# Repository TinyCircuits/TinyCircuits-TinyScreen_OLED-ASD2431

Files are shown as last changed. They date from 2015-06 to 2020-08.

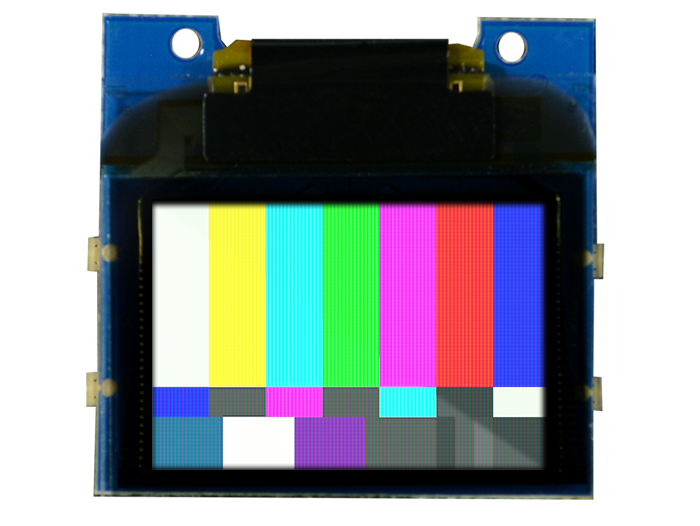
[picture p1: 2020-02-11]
images/ASD2431-R-Tutorial-Image-01.2.png

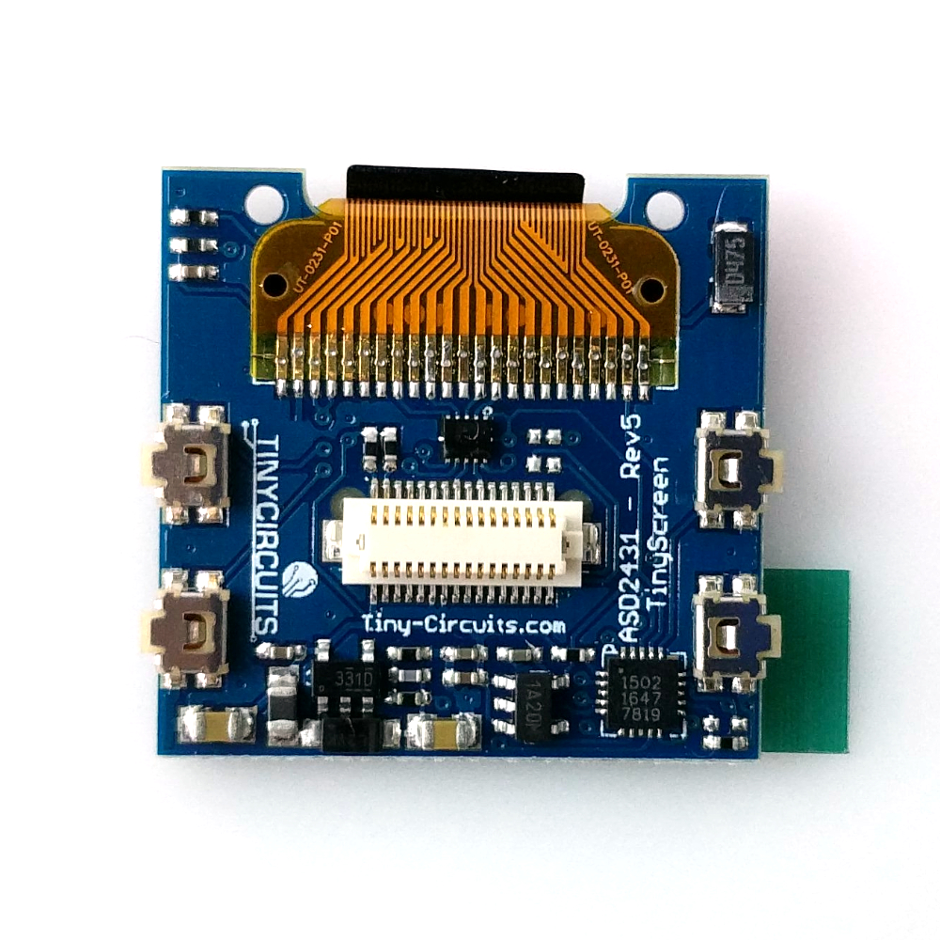
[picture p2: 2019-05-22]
images/ASD2431-R-Tutorial-Image-012.jpg

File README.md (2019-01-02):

# TinyCircuits TinyScreen OLED Display
# ASD2431 Rev6

The design files are located under design_files/ for the TinyCircuits TinyScreen PCB Rev6.  This is a TinyShield board that includes a 96x64 Color OLED Display.  

Format is in Cadsoft Eagle format - Eagle version 6.2 was used for the original design.

For more infomation on this, check out the product page at TinyCircuits.com: https://tinycircuits.com/collections/leds-displays/products/tinyscreen

# License:

Design by TinyCircuits.
All design files are released under the Creative Commons Attribution Share-Alike 3.0 License, see the following link for details: http://creativecommons.org/licenses/by-sa/3.0

All text above must be included in any redistribution or derived design

This project uses designs and concepts developed as part of the Arduino project and the LilyPad project.  The TinyCircuits design files themselves (schematics, PCB and libraries) are not directly derived from these works' design files and have been created new, however the concepts and basic architecture behind the TinyDuino and TinyLily products are derived and we thank the hard work of the organizations below for their contributions to open-source hardware:
  
Original Arduino Uno Design by Team Arduino

LilyPad Arduino Design by Leah Buechley and Sparkfun Electronics

Please support the open-source hardware community

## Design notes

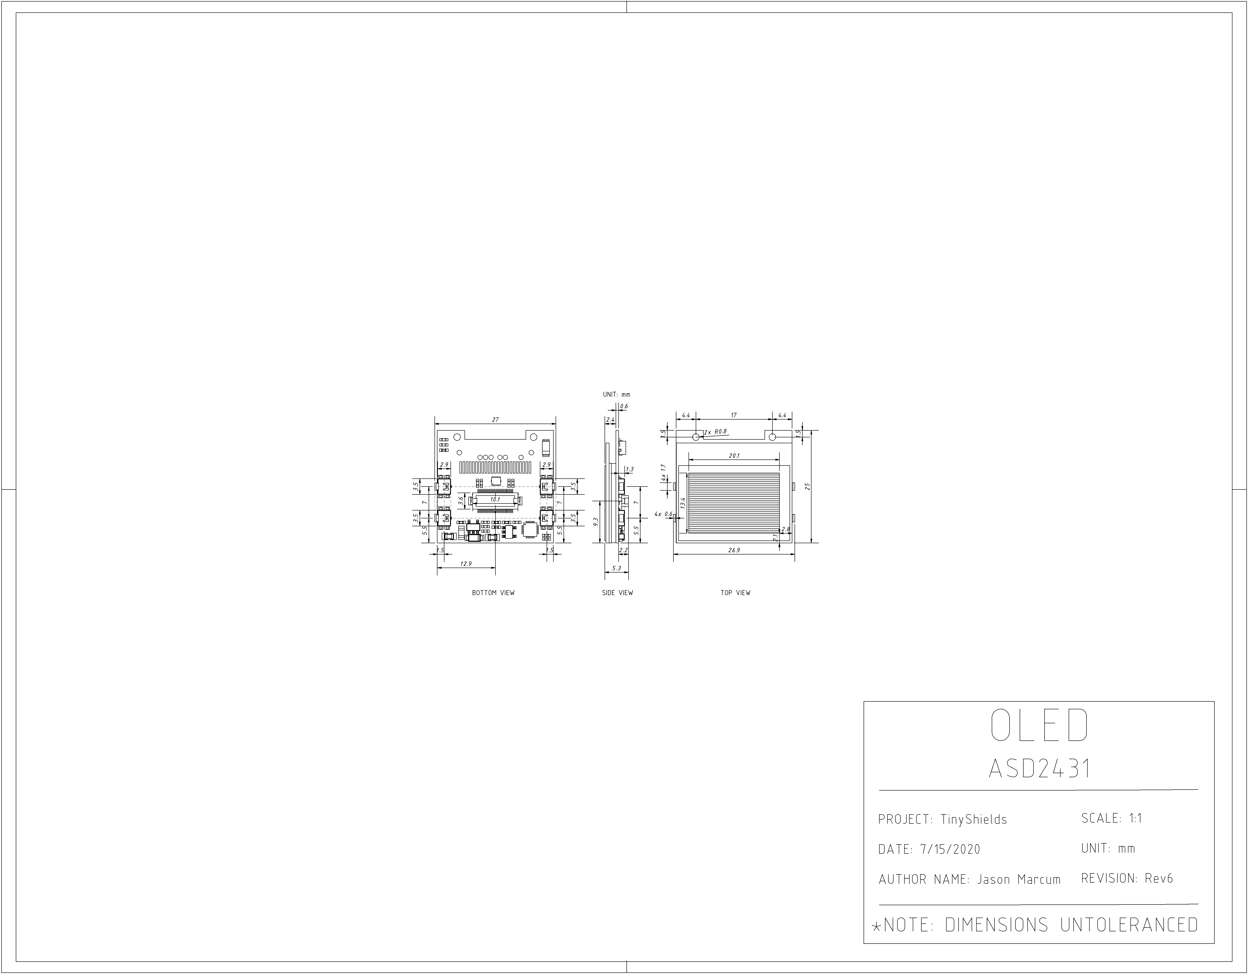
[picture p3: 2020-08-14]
cad/TinyShield_OLED_ASD2431_REV6-DETAILED_DRAWING-PNG.png

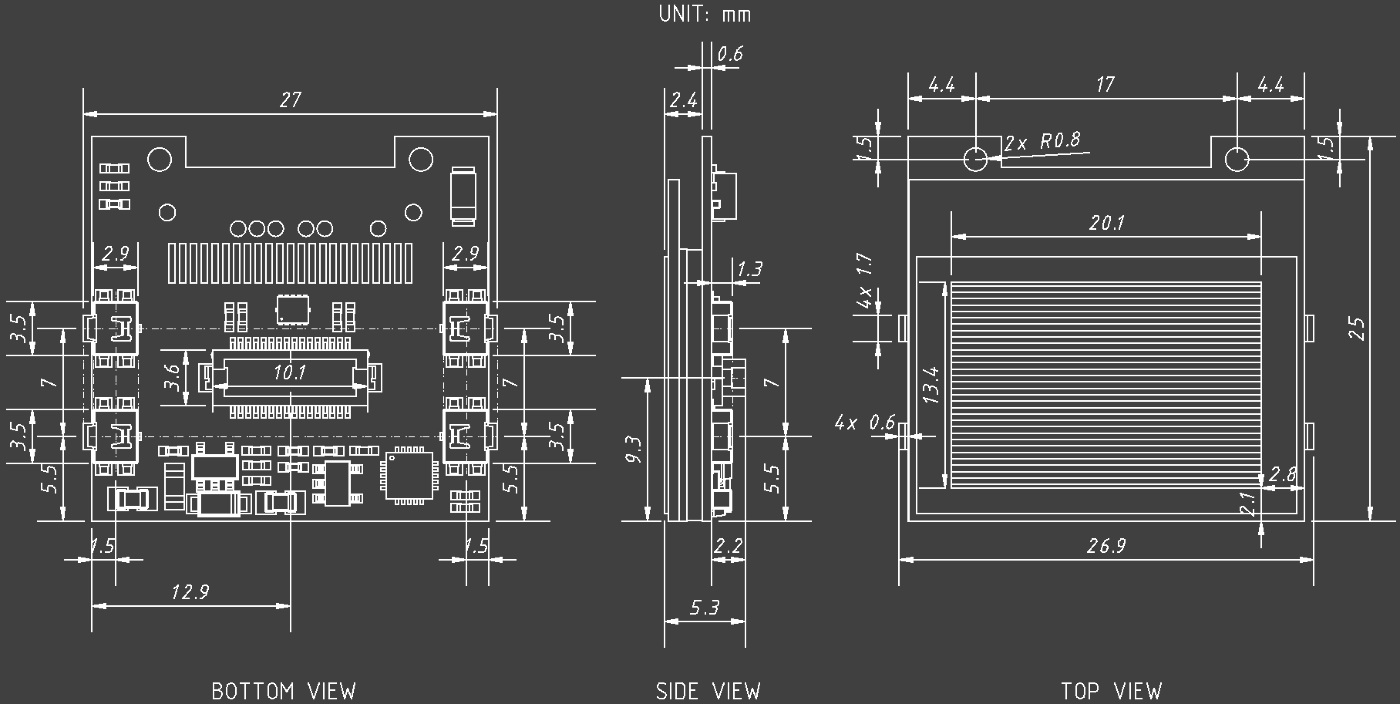
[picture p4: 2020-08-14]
cad/TinyShield_OLED_ASD2431_REV6-DETAILED_DRAWING_COMPACT-PNG.png

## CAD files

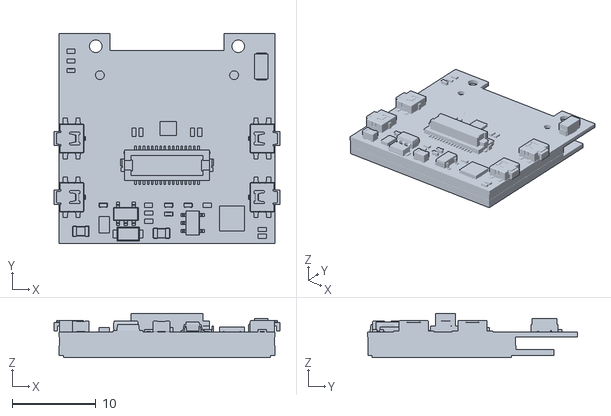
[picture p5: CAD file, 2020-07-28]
cad/TinyShield_OLED_ASD2431_REV6-STL.stl
26.9 x 25.0 x 5.25

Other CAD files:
cad/TinyShield_OLED_ASD2431_REV6-DETAILED_DRAWING-DXF.dxf

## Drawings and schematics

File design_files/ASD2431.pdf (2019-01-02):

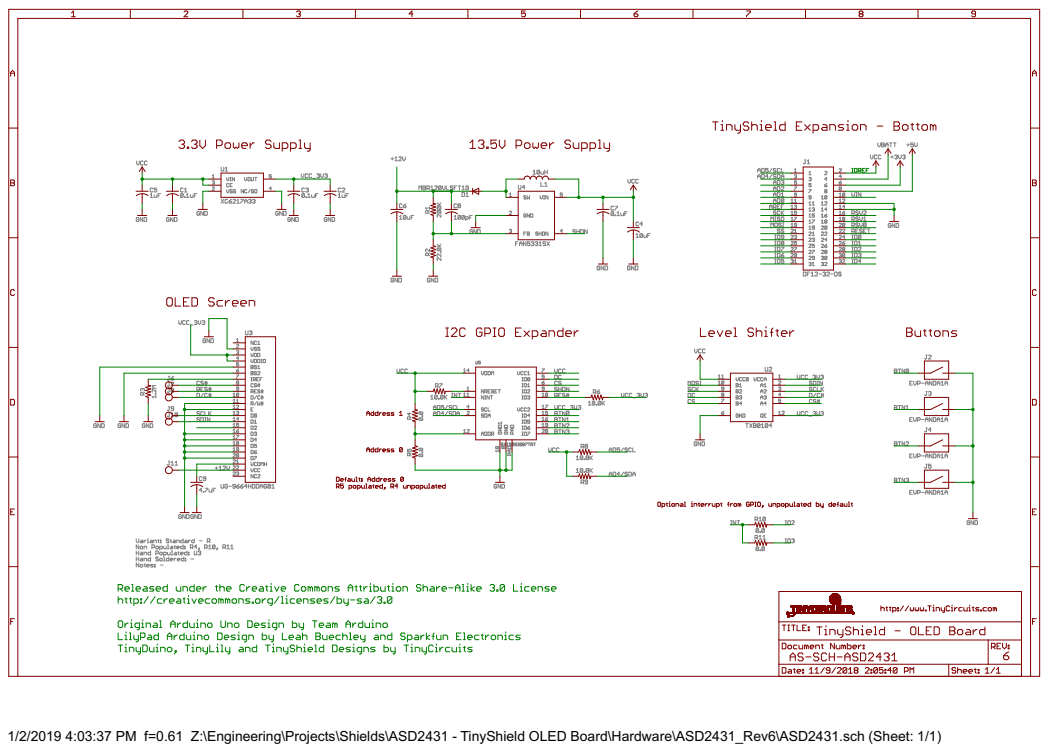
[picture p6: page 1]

1/2/2019 4:03:37 PM f=0.61 Z:\Engineering\Projects\Shields\ASD2431 - TinyShield OLED Board\Hardware\ASD2431_Rev6\ASD2431.sch (Sheet: 1/1)

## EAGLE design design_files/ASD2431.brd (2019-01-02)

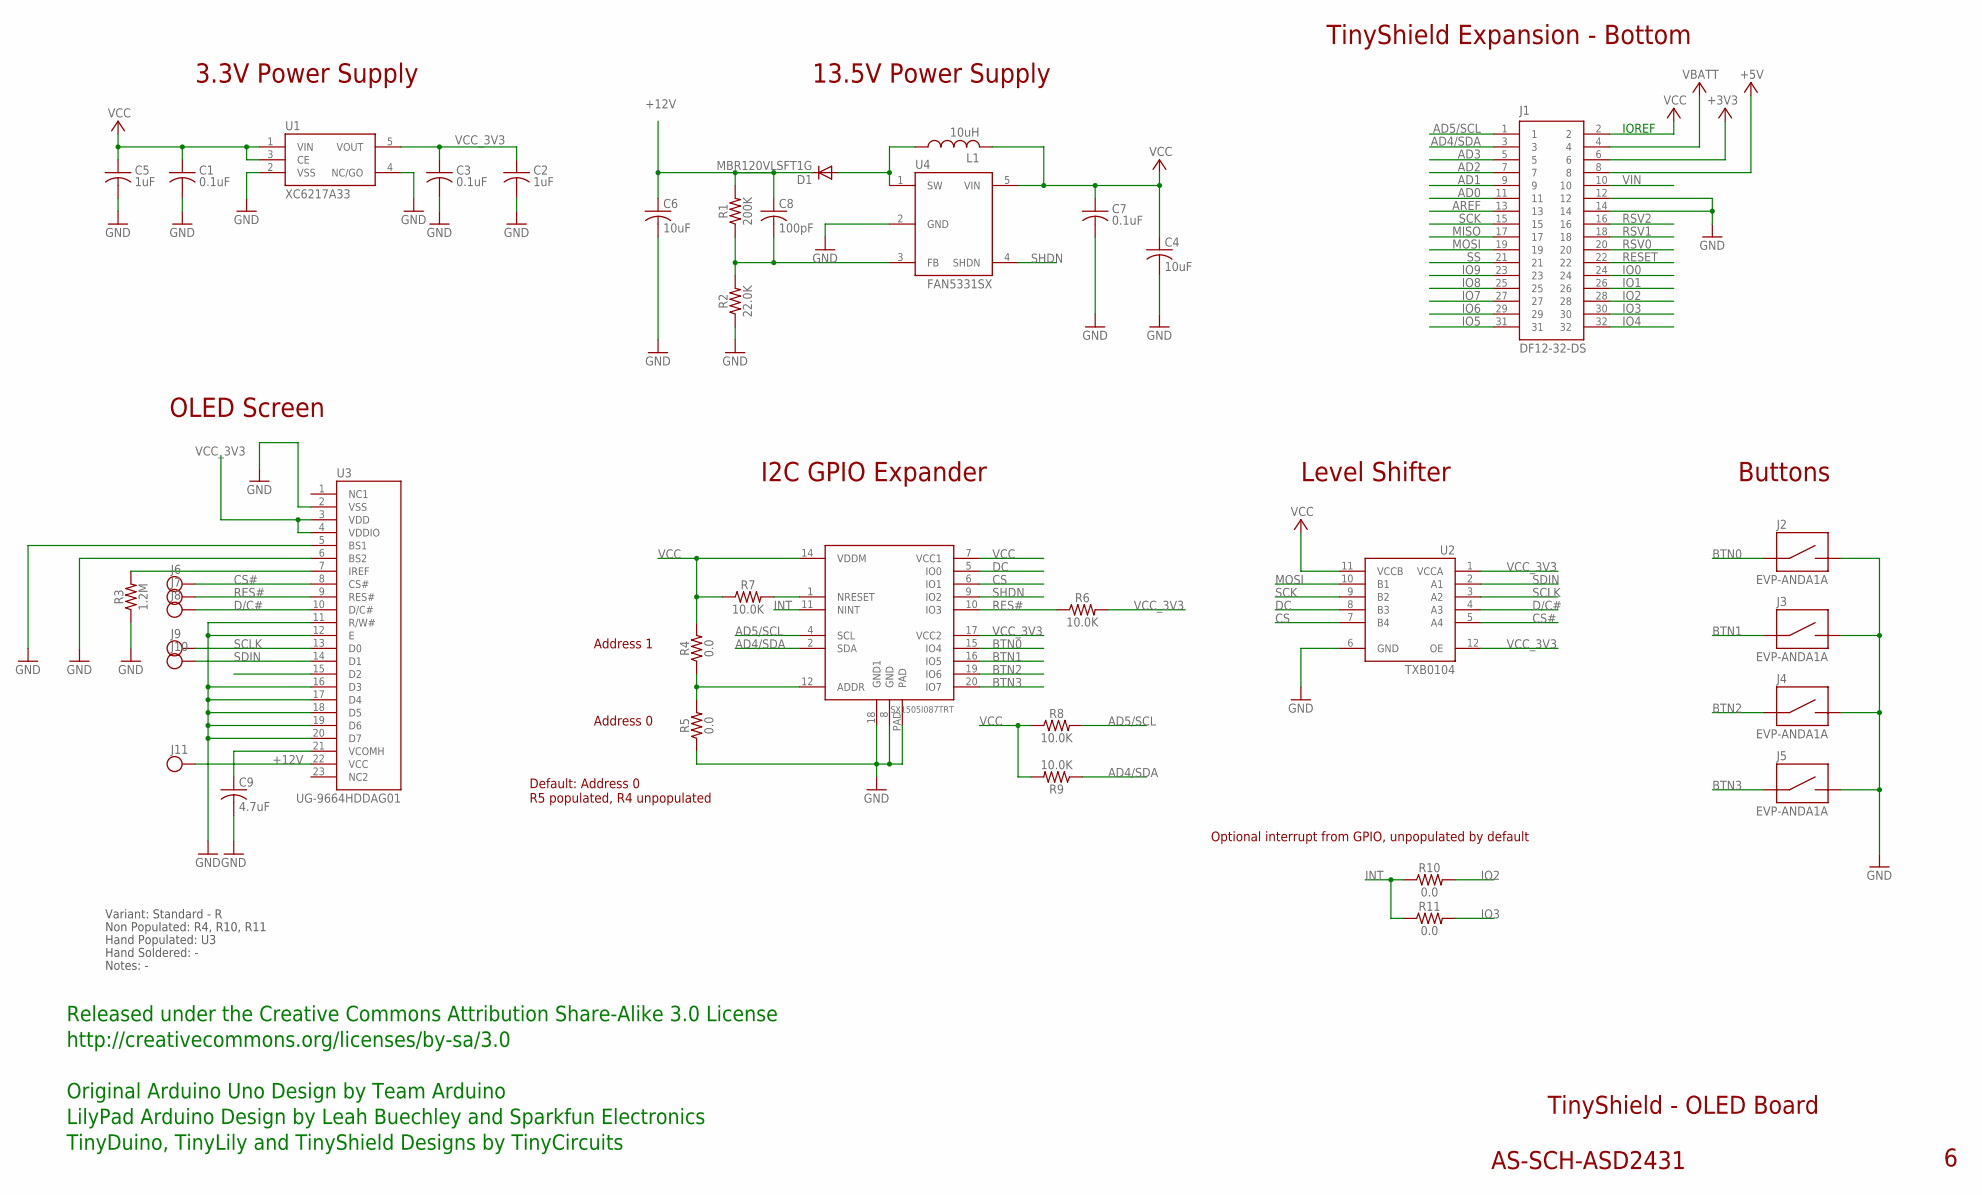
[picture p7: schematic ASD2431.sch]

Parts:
C1, C3, C7: 0.1uF; C0402; PARTNO AS-ITM-00008
C2, C5: 1uF; C0402; PARTNO AS-ITM-00105
C4, C6: 10uF; C0805; PARTNO AS-ITM-00045
C8: 100pF; 0402; PARTNO AS-ITM-00148
C9: 4.7uF; 1206_CAP_TANT; PARTNO AS-ITM-00232
D1: MBR120VLSFT1G; SOD-123FL
J1: DF12-32-DS; PARTNO AS-ITM-00012
J2, J3, J4, J5: EVP-ANDA1A; PTS840GKP; PARTNO AS-ITM-00236
J6, J7, J8, J9, J10, J11: TEST_POINT; TEST_POINT_1MM
L1: 10uH; R0805
R1: 200K; 0402; PARTNO AS-ITM-00178
R2: 22.0K; 0402; PARTNO AS-ITM-00147
R3: 1.2M; 0402; PARTNO AS-ITM-00280
R4, R5: 0.0; 0402
R6: 10.0K; 0402
R7, R8, R9: 10.0K; 0402; PARTNO AS-ITM-00032
R10, R11: 0.0; 0402; PARTNO AS-ITM-00076
U1: XC6217A33; SOT-25; PARTNO AS-ITM-00249
U2: TXB0104; UQFN-12
U3: UG-9664HDDAG01; OLED_DISPLAY
U4: FAN5331SX; SOT-23
U5: SX1505I087TRT; QFN-UT20

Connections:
+3V3: J1.6
+5V: J1.8
+12V: C6.1, C8.1, D1.C, J11.P$1, R1.2, U3.22 (VCC)
AD0: J1.11
AD1: J1.9
AD2: J1.7
AD3: J1.5
AD4/SDA: J1.3, R9.1, U5.2 (SDA)
AD5/SCL: J1.1, R8.2, U5.4 (SCL)
AREF: J1.13
BTN0: J2.1, J2.2 (1), U5.15 (IO4)
BTN1: J3.1, J3.2 (1), U5.16 (IO5)
BTN2: J4.1, J4.2 (1), U5.19 (IO6)
BTN3: J5.1, J5.2 (1), U5.20 (IO7)
CS: U2.7 (B4), U5.6 (IO1)
CS#: J6.P$1, U2.5 (A4), U3.8 (CS#)
D/C#: J8.P$1, U2.4 (A3), U3.10 (D/C#)
DC: U2.8 (B3), U5.5 (IO0)
GND: C1.2, C2.2, C3.2, C4.2, C5.2, C6.2, C7.2, C9.2, J1.12, J1.14, J2.3 (2), J2.4 (2), J3.3 (2), J3.4 (2), J4.3 (2), J4.4 (2), J5.3 (2), J5.4 (2), R2.1, R3.1, R5.1, U1.2 (VSS), U1.4 (NC/GO), U2.6 (GND), U3.2 (VSS), U3.5 (BS1), U3.6 (BS2), U3.11 (R/W#), U3.12 (E), U3.16 (D3), U3.17 (D4), U3.18 (D5), U3.19 (D6), U3.20 (D7), U4.2 (GND), U5.8 (GND), U5.18 (GND1), U5.PAD
INT: R10.1, R11.1, U5.11 (NINT)
IO0: J1.24
IO1: J1.26
IO2: J1.28, R10.2
IO3: J1.30, R11.2
IO4: J1.32
IO5: J1.31
IO6: J1.29
IO7: J1.27
IO8: J1.25
IO9: J1.23
MISO: J1.17
MOSI: J1.19, U2.10 (B1)
unnamed: R7.2, U5.1 (NRESET)
unnamed: D1.A, L1.1, U4.1 (SW)
unnamed: C8.2, R1.1, R2.2, U4.3 (FB)
unnamed: R3.2, U3.7 (IREF)
unnamed: C9.1, U3.21 (VCOMH)
unnamed: R4.1, R5.2, U5.12 (ADDR)
RES#: J7.P$1, R6.1, U3.9 (RES#), U5.10 (IO3)
RESET: J1.22
RSV0: J1.20
RSV1: J1.18
RSV2: J1.16
SCK: J1.15, U2.9 (B2)
SCLK: J9.P$1, U2.3 (A2), U3.13 (D0)
SDIN: J10.P$1, U2.2 (A1), U3.14 (D1)
SHDN: U4.4 (SHDN), U5.9 (IO2)
SS: J1.21
VBATT: J1.4
VCC: C1.1, C4.1, C5.1, C7.1, J1.2, L1.2, R4.2, R7.1, R8.1, R9.2, U1.1 (VIN), U1.3 (CE), U2.11 (VCCB), U4.5 (VIN), U5.7 (VCC1), U5.14 (VDDM)
VCC_3V3: C2.1, C3.1, R6.2, U1.5 (VOUT), U2.1 (VCCA), U2.12 (OE), U3.3 (VDD), U3.4 (VDDIO), U5.17 (VCC2)
VIN: J1.10

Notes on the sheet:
TinyShield Expansion - Bottom
TinyShield - OLED Board
AS-SCH-ASD2431
IOREF
Released under the Creative Commons Attribution Share-Alike 3.0 License
http://creativecommons.org/licenses/by-sa/3.0
LilyPad Arduino Design by Leah Buechley and Sparkfun Electronics
TinyDuino, TinyLily and TinyShield Designs by TinyCircuits
Original Arduino Uno Design by Team Arduino
3.3V Power Supply
13.5V Power Supply
OLED Screen
Level Shifter
I2C GPIO Expander
Buttons
Address 0
Address 1
Default: Address 0 R5 populated, R4 unpopulated
Optional interrupt from GPIO, unpopulated by default
Non Populated: R4, R10, R11
Hand Populated: U3
Hand Soldered: -
Notes: -
Variant: Standard - R

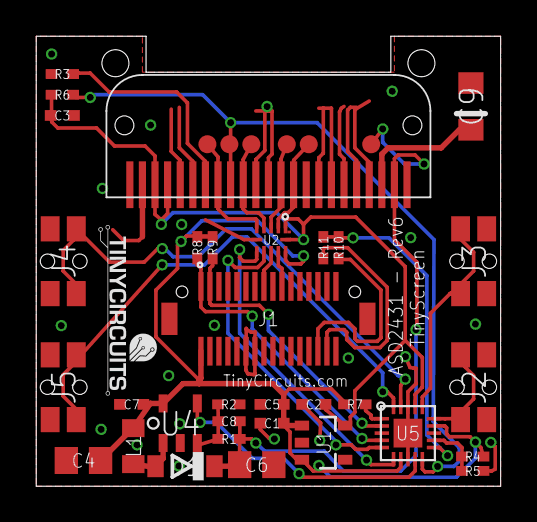
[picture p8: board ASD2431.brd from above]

Board: 2 copper layers, 25.8 x 25.0 mm, 39 parts (0 on the bottom side), 29 nets.

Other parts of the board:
U$1: DOCFIELD-TINYCIRCUITS-PCB

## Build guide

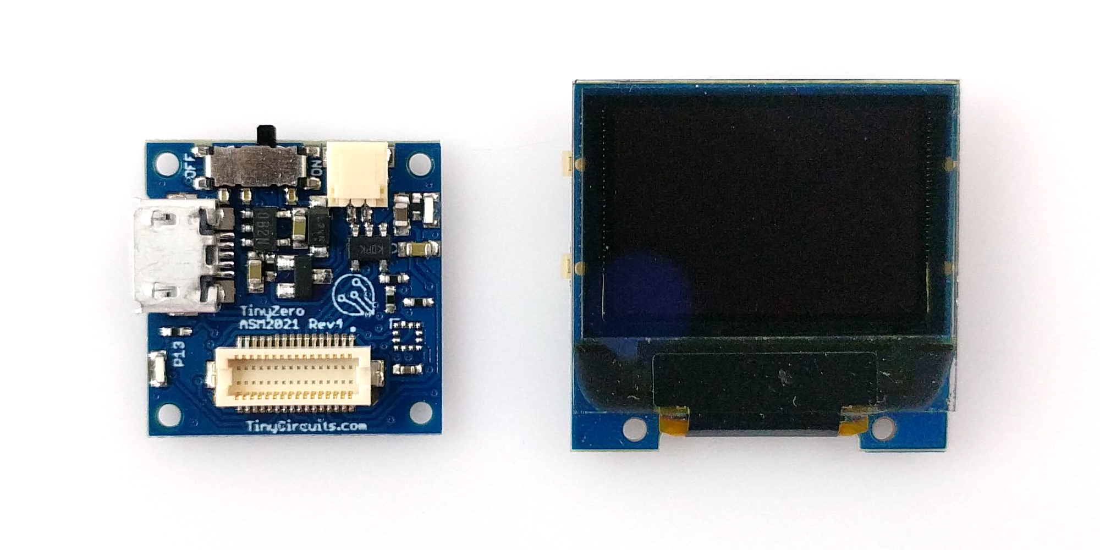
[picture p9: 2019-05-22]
images/ASD2431-R-Tutorial-Image-02.jpg

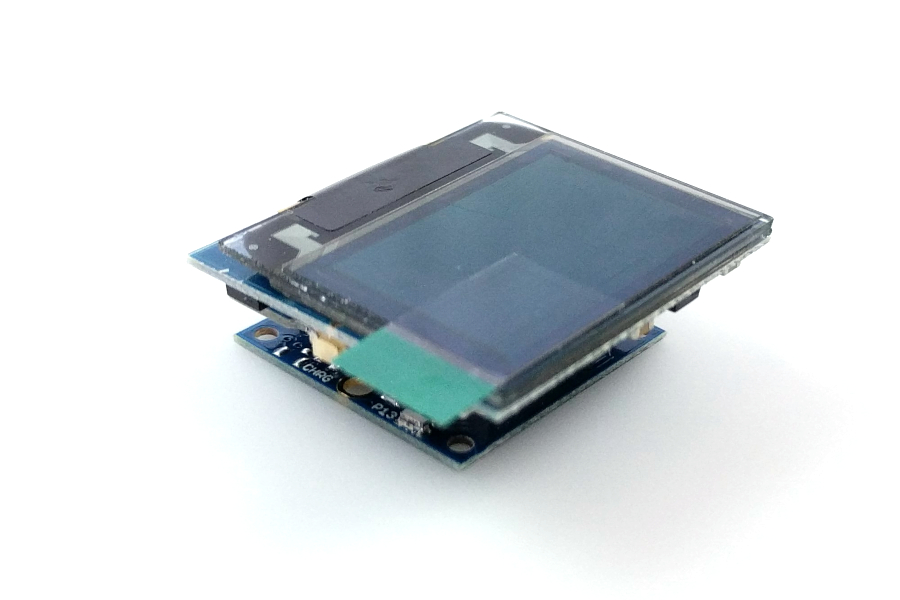
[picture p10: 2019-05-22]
images/ASD2431-R-Tutorial-Image-03.jpg

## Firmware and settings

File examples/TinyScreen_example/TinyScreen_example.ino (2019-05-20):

/*
  TinyCircuits TinyScreen/TinyScreen+ Basic Example
  
  This example shows the basic functionality of the TinyScreen library,
  including drawing, writing bitmaps, and printing text
  
  Written 26 January 2016
  by Ben Rose
  Written 26 January 2016
  By Ben Rose
  Modified 20 May 2019
  By Hunter Hykes
  
  https://TinyCircuits.com
*/

#include <Wire.h>
#include <SPI.h>
#include <TinyScreen.h>

//Library must be passed the board type
//TinyScreenDefault for TinyScreen shields
//TinyScreenAlternate for alternate address TinyScreen shields
//TinyScreenPlus for TinyScreen+
TinyScreen display = TinyScreen(TinyScreenDefault);

//This is an example 17x12 pixel bitmap using TS library color definitions
unsigned char flappyBirdBitmap[204]={
  TS_8b_Blue,TS_8b_Blue,TS_8b_Blue,TS_8b_Blue,TS_8b_Blue,TS_8b_Blue,TS_8b_Black,TS_8b_Black,TS_8b_Black,TS_8b_Black,TS_8b_Black,TS_8b_Black,TS_8b_Blue,TS_8b_Blue,TS_8b_Blue,TS_8b_Blue,TS_8b_Blue,
  TS_8b_Blue,TS_8b_Blue,TS_8b_Blue,TS_8b_Blue,TS_8b_Black,TS_8b_Black,TS_8b_White,TS_8b_White,TS_8b_White,TS_8b_Black,TS_8b_White,TS_8b_White,TS_8b_Black,TS_8b_Blue,TS_8b_Blue,TS_8b_Blue,TS_8b_Blue,
  TS_8b_Blue,TS_8b_Blue,TS_8b_Blue,TS_8b_Black,TS_8b_White,TS_8b_White,TS_8b_Yellow,TS_8b_Yellow,TS_8b_Black,TS_8b_White,TS_8b_White,TS_8b_White,TS_8b_White,TS_8b_Black,TS_8b_Blue,TS_8b_Blue,TS_8b_Blue,
  TS_8b_Blue,TS_8b_Black,TS_8b_Black,TS_8b_Black,TS_8b_Black,TS_8b_Yellow,TS_8b_Yellow,TS_8b_Yellow,TS_8b_Black,TS_8b_White,TS_8b_White,TS_8b_White,TS_8b_Black,TS_8b_White,TS_8b_Black,TS_8b_Blue,TS_8b_Blue,
  TS_8b_Black,TS_8b_White,TS_8b_White,TS_8b_White,TS_8b_White,TS_8b_Black,TS_8b_Yellow,TS_8b_Yellow,TS_8b_Black,TS_8b_White,TS_8b_White,TS_8b_White,TS_8b_Black,TS_8b_White,TS_8b_Black,TS_8b_Blue,TS_8b_Blue,
  TS_8b_Black,TS_8b_White,TS_8b_White,TS_8b_White,TS_8b_White,TS_8b_White,TS_8b_Black,TS_8b_Yellow,TS_8b_Yellow,TS_8b_Black,TS_8b_White,TS_8b_White,TS_8b_White,TS_8b_White,TS_8b_Black,TS_8b_Blue,TS_8b_Blue,
  TS_8b_Black,TS_8b_Yellow,TS_8b_White,TS_8b_White,TS_8b_White,TS_8b_Yellow,TS_8b_Black,TS_8b_Yellow,TS_8b_Yellow,TS_8b_Yellow,TS_8b_Black,TS_8b_Black,TS_8b_Black,TS_8b_Black,TS_8b_Black,TS_8b_Black,TS_8b_Blue,
  TS_8b_Blue,TS_8b_Black,TS_8b_Yellow,TS_8b_Yellow,TS_8b_Yellow,TS_8b_Black,TS_8b_Yellow,TS_8b_Yellow,TS_8b_Yellow,TS_8b_Black,TS_8b_Red,TS_8b_Red,TS_8b_Red,TS_8b_Red,TS_8b_Red,TS_8b_Red,TS_8b_Black,
  TS_8b_Blue,TS_8b_Blue,TS_8b_Black,TS_8b_Black,TS_8b_Black,TS_8b_Yellow,TS_8b_Yellow,TS_8b_Yellow,TS_8b_Yellow,TS_8b_Black,TS_8b_Red,TS_8b_Black,TS_8b_Black,TS_8b_Black,TS_8b_Black,TS_8b_Black,TS_8b_Black,
  TS_8b_Blue,TS_8b_Blue,TS_8b_Black,TS_8b_Yellow,TS_8b_Yellow,TS_8b_Yellow,TS_8b_Yellow,TS_8b_Yellow,TS_8b_Yellow,TS_8b_Black,TS_8b_Red,TS_8b_Red,TS_8b_Red,TS_8b_Red,TS_8b_Red,TS_8b_Black,TS_8b_Blue,
  TS_8b_Blue,TS_8b_Blue,TS_8b_Blue,TS_8b_Black,TS_8b_Black,TS_8b_Yellow,TS_8b_Yellow,TS_8b_Yellow,TS_8b_Yellow,TS_8b_Yellow,TS_8b_Black,TS_8b_Black,TS_8b_Black,TS_8b_Black,TS_8b_Black,TS_8b_Blue,TS_8b_Blue,
  TS_8b_Blue,TS_8b_Blue,TS_8b_Blue,TS_8b_Blue,TS_8b_Blue,TS_8b_Black,TS_8b_Black,TS_8b_Black,TS_8b_Black,TS_8b_Black,TS_8b_Blue,TS_8b_Blue,TS_8b_Blue,TS_8b_Blue,TS_8b_Blue,TS_8b_Blue,TS_8b_Blue
};

void setup(void) {
  Wire.begin();//initialize I2C before we can initialize TinyScreen- not needed for TinyScreen+
  display.begin();
  //setBrightness(brightness);//sets main current level, valid levels are 0-15
  display.setBrightness(10);
}

void loop() {
  hardwareDrawCommands();
  drawPixels();
  drawBitmap();
  //setFlip(boolean);//done in hardware on the SSD1331
  display.setFlip(true);
  delay(1000);
  display.setFlip(false);
  delay(1000);
  writeText();
  delay(1000);
  readInput();
}

void hardwareDrawCommands(){
  //Accelerated drawing commands are executed by the display controller
  //clearScreen();//clears entire display- the same as clearWindow(0,0,96,64)
  display.clearScreen();
  //drawRect(x stary, y start, width, height, fill, 8bitcolor);//sets specified OLED controller memory to an 8 bit color, fill is a boolean- TSRectangleFilled or TSRectangleNoFill
  display.drawRect(10,10,76,44,TSRectangleFilled,TS_8b_Red);
  //drawRect(x stary, y start, width, height, fill, red, green, blue);//like above, but uses 6 bit color values. Red and blue ignore the LSB.
  display.drawRect(15,15,66,34,TSRectangleFilled,20,30,60);
  //clearWindow(x start, y start, width, height);//clears specified OLED controller memory
  display.clearWindow(20,20,56,24);
  //drawLine(x1, y1, x2, y2, 8bitcolor);//draw a line from (x1,y1) to (x2,y2) with an 8 bit color
  display.drawLine(0,0,95,63,TS_8b_Green);
  //drawLine(x1, y1, x2, y2, red, green, blue);//like above, but uses 6 bit color values. Red and blue ignore the LSB.
  display.drawLine(0,63,95,0,0,63,0);
  delay(1000);
  //use 16 bit version of drawLine to fade a rectangle from blue to green:
  for(int i=0;i<64;i++){
    display.drawLine(0,i,95,i,0,i,63-i);
  }
  delay(1000);
}

void drawPixels(){
  //writing pixels one by one is slow, but neccessary for drawing shapes other than lines and rectangles
  //we'll implement a simple circle drawing algorithm from http://en.wikipedia.org/wiki/Midpoint_circle_algorithm
  drawCircle(40,30,30,TS_8b_Red);
  drawCircle(45,30,25,TS_8b_Yellow);
  drawCircle(50,30,20,TS_8b_Blue);
  drawCircle(55,30,15,TS_8b_Brown);
  drawCircle(60,30,10,TS_8b_Green);
  drawCircle(65,30,5,TS_8b_Black);
  delay(1000);
}

void drawCircle(int x0, int y0, int radius, uint8_t color)
{
  int x = radius;
  int y = 0;
  int radiusError = 1-x;
 
  while(x >= y)
  {
    //drawPixel(x,y,color);//set pixel (x,y) to specified color. This is slow because we need to send commands setting the x and y, then send the pixel data.
    display.drawPixel(x + x0, y + y0, color);
    display.drawPixel(y + x0, x + y0, color);
    display.drawPixel(-x + x0, y + y0, color);
    display.drawPixel(-y + x0, x + y0, color);
    display.drawPixel(-x + x0, -y + y0, color);
    display.drawPixel(-y + x0, -x + y0, color);
    display.drawPixel(x + x0, -y + y0, color);
    display.drawPixel(y + x0, -x + y0, color);
    y++;
    if (radiusError<0)
    {
      radiusError += 2 * y + 1;
    }
    else
    {
      x--;
      radiusError += 2 * (y - x) + 1;
    }
  }
}

void drawBitmap(){
  //set a background that matches
  display.drawRect(0,0,96,64,TSRectangleFilled,TS_8b_Blue);
  //let's set up for a bitmap at (40,30) that is 17 pixels wide and 12 pixels tall:
  //setX(x start, x end);//set OLED RAM to x start, wrap around at x end
  display.setX(40,40+17-1);
  //setY(y start, y end);//set OLED RAM to y start, wrap around at y end
  display.setY(30,30+12-1);
  //now start a data transfer
  display.startData();
  //writeBuffer(buffer,count);//optimized write of a large buffer of 8 bit data.
  display.writeBuffer(flappyBirdBitmap,17*12);
  display.endTransfer();
  delay(1000);
  
}

void writeText(){
  display.clearScreen();
  //setFont sets a font info header from font.h
  //information for generating new fonts is included in font.h
  display.setFont(thinPixel7_10ptFontInfo);
  //getPrintWidth(character array);//get the pixel print width of a string
  int width=display.getPrintWidth("Example Text!");
  //setCursor(x,y);//set text cursor position to (x,y)- in this example, the example string is centered
  display.setCursor(48-(width/2),10);
  //fontColor(text color, background color);//sets text and background color
  display.fontColor(TS_8b_Green,TS_8b_Black);
  display.print("Example Text!");
  display.setCursor(15,25);
  display.fontColor(TS_8b_Blue,TS_8b_Black);
  display.print("More example Text!");
  display.setCursor(3,40);
  display.fontColor(TS_8b_Red,TS_8b_Black);
  display.print("(Does not wrap)");
  delay(1000);
}

void readInput() {
  display.fontColor(TS_8b_White,TS_8b_Black);
  display.clearScreen();
  display.setCursor(48 - (display.getPrintWidth("Press a Button!") / 2), 32 - (display.getFontHeight() / 2));
  display.print("Press a Button!");
  unsigned long startTime = millis();
  while (millis() - startTime < 3000)buttonLoop();
  display.clearScreen();
  display.setFlip(true);
  display.setCursor(48 - (display.getPrintWidth("Press a Button!") / 2), 32 - (display.getFontHeight() / 2));
  display.print("Press a Button!");
  startTime = millis();
  while (millis() - startTime < 3000)buttonLoop();
  display.clearScreen();
  display.setFlip(false);
}

void buttonLoop() {
  display.setCursor(0, 0);
  //getButtons() function can be used to test if any button is pressed, or used like:
  //getButtons(TSButtonUpperLeft) to test a particular button, or even like:
  //getButtons(TSButtonUpperLeft|TSButtonUpperRight) to test multiple buttons
  //results are flipped as you would expect when setFlip(true)
  if (display.getButtons(TSButtonUpperLeft)) {
    display.println("Pressed!");
  } else {
    display.println("          ");
  }
  display.setCursor(0, 54);
  if (display.getButtons(TSButtonLowerLeft)) {
    display.println("Pressed!");
  } else {
    display.println("          ");
  }
  display.setCursor(95 - display.getPrintWidth("Pressed!"), 0);
  if (display.getButtons(TSButtonUpperRight)) {
    display.println("Pressed!");
  } else {
    display.println("          ");
  }
  display.setCursor(95 - display.getPrintWidth("Pressed!"), 54);
  if (display.getButtons(TSButtonLowerRight)) {
    display.println("Pressed!");
  } else {
    display.println("          ");
  }
}

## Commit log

2015-06-07 Update to rev 5
    [ASD2431.brd, ASD2431.sch]
2019-01-02 update files
    [ASD2431.brd, ASD2431.sch]
2020-07-28 Add CAD data
    [TinyShield_OLED_ASD2431_REV6-DETAILED_DRAWING-DXF.dxf, TinyShield_OLED_ASD2431_REV6-STL.stl]
2020-08-14 Update CAD drawing
    [TinyShield_OLED_ASD2431_REV6-DETAILED_DRAWING-DXF.dxf]
